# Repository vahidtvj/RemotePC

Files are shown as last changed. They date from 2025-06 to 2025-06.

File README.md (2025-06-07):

# RemotePC
> An ESP8266 powered PC addon card to remotely power it on using mqtt

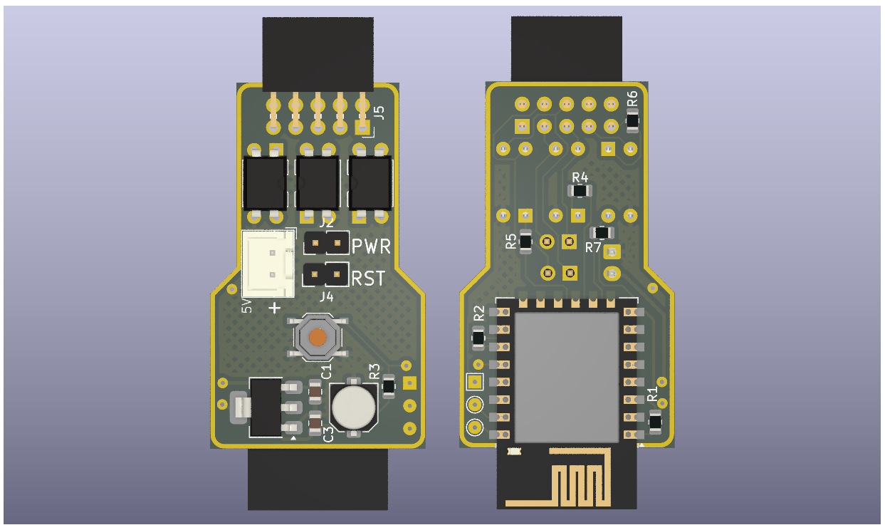
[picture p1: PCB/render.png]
PCB


## How to Build
You need a server to run your mqtt broker on. You can skip this and use a ready made service. The default setup runs MQTT over websocket with TLS. The PCB is designed to be printable at home ( All vias are open and accessible. THT components are soldered only from the other side. )
- Server
  - Get a server. A container even with host routing (no dedicated IP) would do
  - Generate passwords for your mqtt client and the ESP store them in `passwd`
  - After running the server make sure it works with the given test scripts

- ESP board
  - Create a secrets file and also fill in your servers CA certificate in `main.h`
  - For programming use the 3 test points. Hold the button before plugging power to set ESP to bootloader mode
  - Flash the ESP. You should be able to test it with the led command (will flash the on board LED)

The board is designed to be powered from PC 5V Standby. You can plug in your power and reset buttons to the header pins on the board

### Testing

Inside the `test` folder, JavaScript files can be run with Node.js to subscribe to or publish MQTT topics as tests.

### MQTT Topics

- `/pc_led`  
  Payload: `"on"` or `"off"`  
  Controls the onboard LED (on = LED ON, off = LED OFF).

- `/pc`    
  - `"get"`: Publishes current PC power state on `/pc_state` (`"on"` or `"off"`).  
  - `"power"`: Toggles PC power by pulsing the power pin.  
  - `"reset"`: Pulses the reset pin to reset the PC.

## License
[MIT](https://github.com/vahidtvj/RemotePC/blob/master/LICENCE) © [vahidtvj](https://github.com/vahidtvj)

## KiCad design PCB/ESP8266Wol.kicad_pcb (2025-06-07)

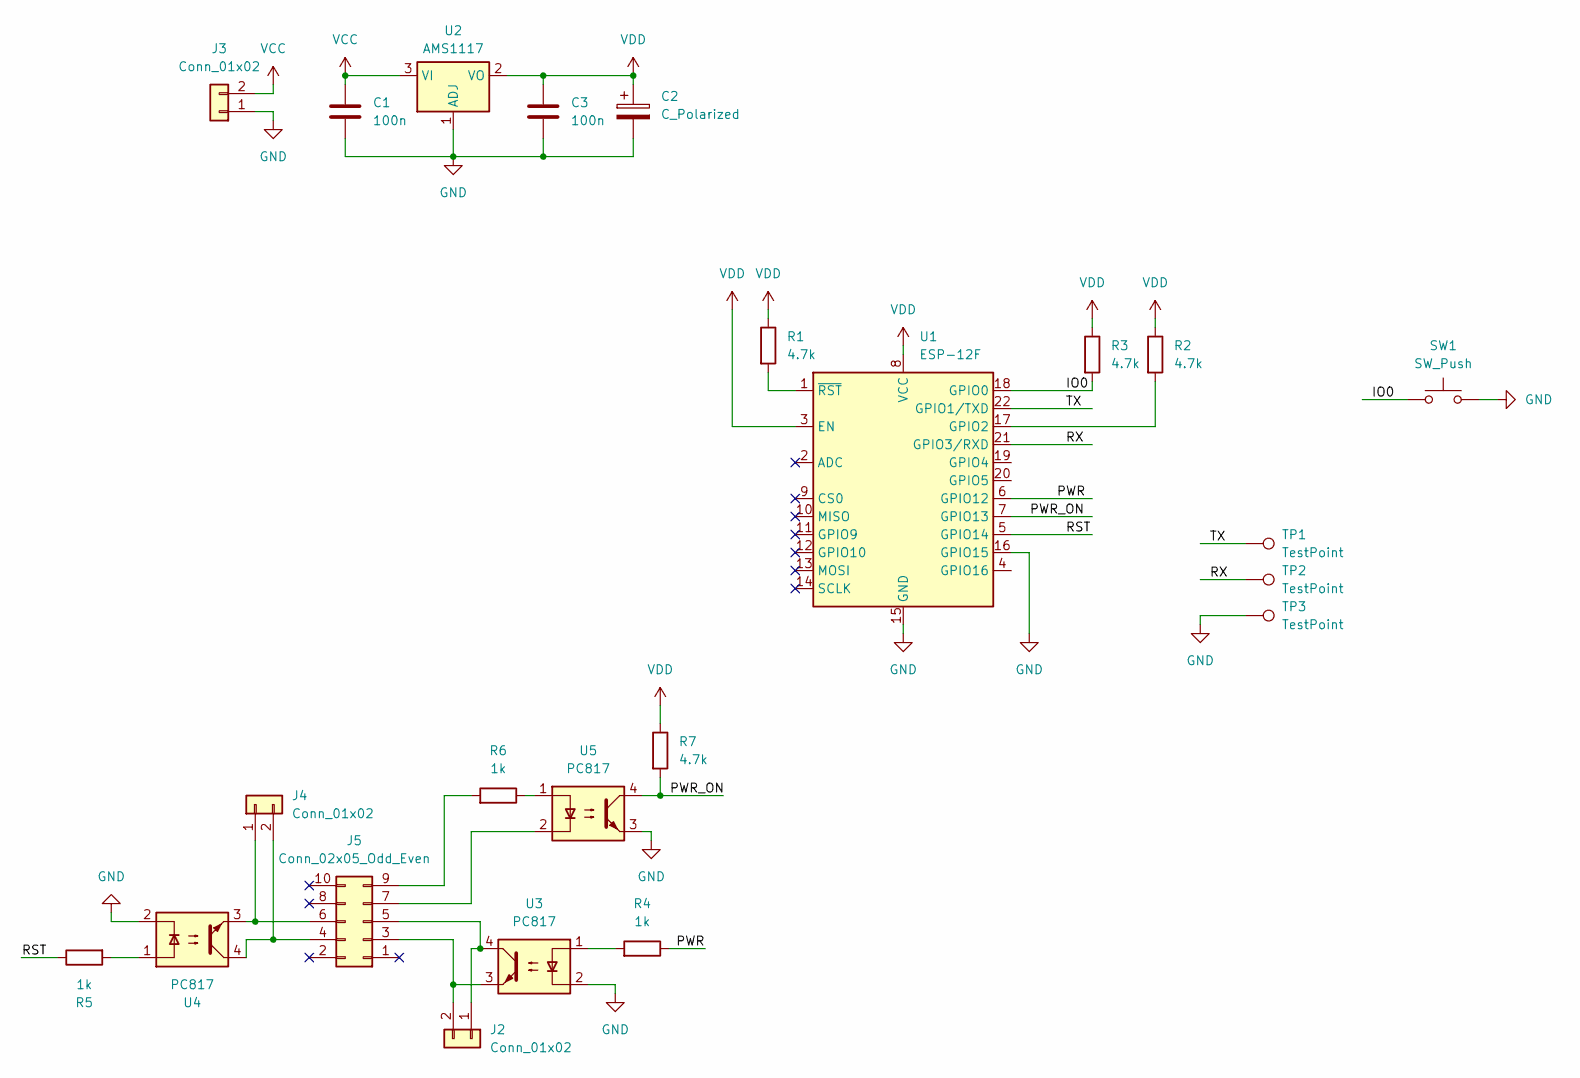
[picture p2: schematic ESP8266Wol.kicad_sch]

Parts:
C1, C3: 100n; C_0805_2012Metric
C2: C_Polarized; C_Elec_5x5.4
J2, J4: Conn_01x02; PinHeader_1x02_P2.54mm_Vertical
J3: Conn_01x02; JST_XH_B2B-XH-A_1x02_P2.50mm_Vertical
J5: Conn_02x05_Odd_Even; PinSocket_2x05_P2.54mm_Horizontal
R1, R2, R3, R7: 4.7k; R_0805_2012Metric
R4, R5, R6: 1k; R_0805_2012Metric
SW1: SW_Push; SW_Push_1P1T_XKB_TS-1187A
TP1, TP2: TestPoint; TestPoint_Pad_D1.5mm
TP3: TestPoint; TestPoint_Pad_1.5x1.5mm
U1: ESP-12F; ESP-12E
U2: AMS1117; SOT-223-3_TabPin2
U3, U4, U5: PC817; DIP-4_W7.62mm

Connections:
/IO0: R3.2, SW1.1, U1.18 (GPIO0)
/PWR: R4.1, U1.6 (GPIO12)
/PWR_ON: R7.2, U1.7 (GPIO13), U5.4
/RST: R5.1, U1.5 (GPIO14)
/RX: TP2.1, U1.21 (GPIO3/RXD)
/TX: TP1.1, U1.22 (GPIO1/TXD)
GND: C1.2, C2.2, C3.2, J3.1, SW1.2, TP3.1, U1.15 (GND), U1.16 (GPIO15), U2.1 (ADJ), U3.2, U4.2, U5.3
unnamed: J2.1, J5.5, U3.4
unnamed: J2.2, J5.3, U3.3
unnamed: J4.1, J5.6, U4.3
unnamed: J4.2, J5.4, U4.4
unnamed: J5.7, U5.2
unnamed: J5.9, R6.2
unnamed: R4.2, U3.1
unnamed: R5.2, U4.1
unnamed: R6.1, U5.1
unnamed: R2.2, U1.17 (GPIO2)
unnamed: R1.2, U1.1 (~RST)
VCC: C1.1, J3.2, U2.3 (VI)
VDD: C2.1, C3.1, R1.1, R2.1, R3.1, R7.1, U1.3 (EN), U1.8 (VCC), U2.2 (VO)

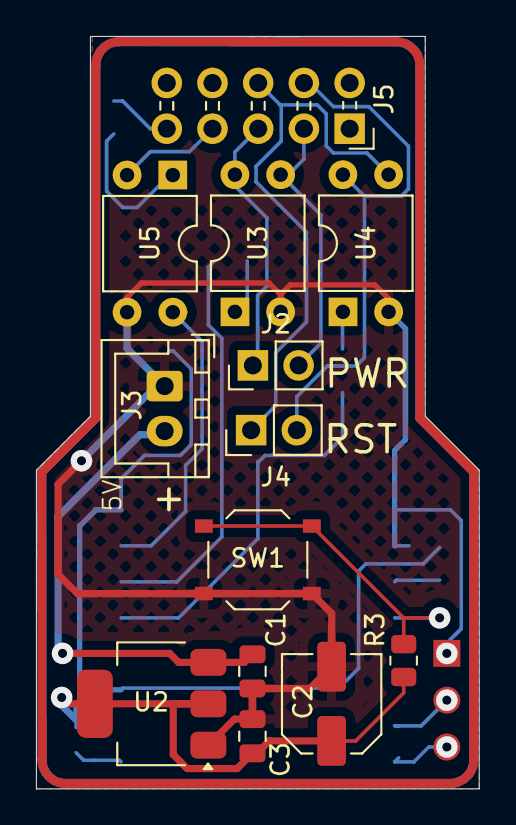
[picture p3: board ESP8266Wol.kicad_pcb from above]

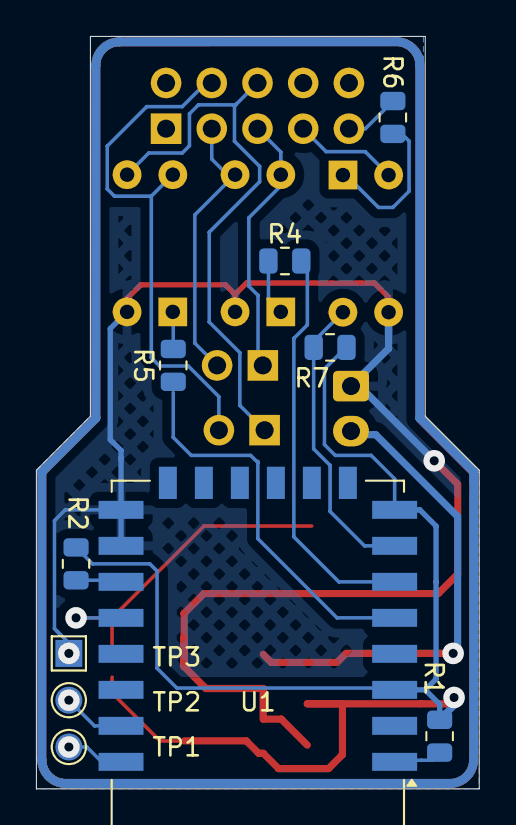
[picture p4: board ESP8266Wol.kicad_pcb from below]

Board: 2 copper layers, 24.6 x 41.8 mm, 23 parts (10 on the bottom side), 20 nets.

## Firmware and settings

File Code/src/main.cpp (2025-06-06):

#include "main.h"
#include "network.tpp"

void subscribeMQTT()
{
  mqtt.subscribe("/pc_led", [](const String &payload, const size_t size)
                 {
                  if(payload=="on")
                    digitalWrite(LED, LOW);
                  if (payload == "off")
                    digitalWrite(LED, HIGH); });

  mqtt.subscribe("/pc", [](const String &payload, const size_t size)
                 {
                  if(payload=="get")
                  {
                    mqtt.publish("/pc_state", digitalRead(IN_POWER_LED)==HIGH? "off":"on");
                    return;
                  }
                  if(payload!="power"&& payload != "reset") return;
                  uint8 pin=payload=="power"? OUT_PWR: OUT_RST;
                  digitalWrite(pin, HIGH);
                  delay(500);
                  digitalWrite(pin, LOW); });
}

void setup()
{
  pinMode(LED, OUTPUT);
  pinMode(OUT_PWR, OUTPUT);
  pinMode(OUT_RST, OUTPUT);
  digitalWrite(LED, LOW);
  digitalWrite(OUT_PWR, LOW);
  digitalWrite(OUT_RST, LOW);

#ifdef DEBUG
  Serial.begin(115200);
#endif

  while (!initWiFi())
    yield();
  DEBUG_PRINTLN(WiFi.localIP());

  ArduinoOTA.begin();

  while (!syncNTPTime(30000))
  {
    for (int i = 0; i < 1000; i++) // Approximate 1-second wait
    {
      ArduinoOTA.handle(); // Allow OTA updates
      yield();             // Keep Wi-Fi alive and prevent watchdog resets
    }
  }
  DEBUG_PRINTLN(F(" ntp synced!"));

  client.setReconnectInterval(15000);     // Increase to 15 sec to avoid rapid reconnects
  client.enableHeartbeat(30000, 5000, 3); // Ping every 30 sec, wait 5 sec for pong

  client.beginSslWithCA(SERVER_URL, 443, SERVER_PATH, ENDPOINT_CA_CERT, "mqtt");

  mqtt.begin(client);
  mqtt.setKeepAliveSendInterval(30000); // Send keep-alive every 30 sec
  mqtt.setKeepAliveTimeout(60);         // Ensure it matches broker timeout

  while (!connectMQTT())
  {
    for (int i = 0; i < 1000; i++) // Approximate 1-second wait
    {
      ArduinoOTA.handle(); // Allow OTA updates
      yield();             // Keep Wi-Fi alive and prevent watchdog resets
    }
  }

  subscribeMQTT();

  digitalWrite(LED, HIGH);
}

void loop()
{

  ArduinoOTA.handle();
  mqtt.update(); // should be called

  if (!mqtt.isConnected())
  {
    connectMQTT();
    yield();
    subscribeMQTT();
  }
}
